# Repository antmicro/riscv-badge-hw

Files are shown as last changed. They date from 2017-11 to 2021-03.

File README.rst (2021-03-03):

==========================
RISC-V Electronic Badge HW
==========================

Copyright (c) 2017-2021 `Antmicro <https://www.antmicro.com>`_



Overview:
=========

This repository contains all the hardware design files required to build the RISC-V Electronic Badge development kit. The Badge allows for displaying text and graphics
on an e-Paper screen. The actual content to be displayed can be written to the EEPROM memory using an NFC programmer. The Badge contains a PCB module with a RISC-V based microcontroller
(SiFive's FE310) that reads the content of the EEPROM memory and transfers it to the e-Paper.

Key features:
=============

* 32-bit RISC-V based SiFive FE310 microcontroller placed on a tiny PCB module that can be re-used with a custom baseboard
* EG020BS011 2" e-Paper display
* NFC/RFID tag with 64Kbit EEPROM
* debug USB-JTAG/UART interface (FT4232H) allows the board to be used as an evaluation board
* battery powered (2x CR2032) / 5V over microUSB
* SiLabs EFR32-based ARTIK-030-AV1R IoT module with Bluetooth support (optional)

The device consists of two boards:

1. Badge board equipped with an e-Paper display and all the interfaces and peripherals (`FE310_Badge <FE310_Badge>`_ directory)
2. FE310 Module built around SiFive's FE310 RISC-V chip (`FE310_Module <FE310_Module>`_ directory)

The PCB projects were created in Altium Designer 14.1.

Software support:
=================

The software supporting this hardware platform can be found in a separate repository `here <https://github.com/antmicro/riscv-badge-application>`_.

Acknowledgements:
=================

This project was made possible thanks to the joint effort of Antmicro, SiFive and the RISC-V Foundation on the occasion of the 7th RISC-V Workshop.
If you have any questions, please write to contact@antmicro.com.

License
=======

`Apache-2.0 <LICENSE>`_

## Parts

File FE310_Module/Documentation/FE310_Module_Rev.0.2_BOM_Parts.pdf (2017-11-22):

# Bill of Materials

Project: | FE310 Module
Revision: | 0.2
Variant: | None
Creation Date: | 10/20/2017
Print Date: | 2017/11/22
Value | Footprint | Designator | Description | Manufacturer | Part Symbol | Quantity
100n | 0402 | C1, C2, C5, C6, C7, C8, C9, C10, C14 | MLCC SMT Capacitor 100nF 0402 | MULTICOMP | MC0402X104M100CT | 9
10u | 0402 | C3, C4, C13, C15, C18 | MLCC SMT Capacitor 10uF 0402 | TDK | C1005X5R0J106M050BC | 5 2
12p | 0402 | C11, C12 | MLCC SMT Capacitor 12pF 0402 | WALSIN | 0402N120J500CT
3n3 | 0402 | C16 | MLCC SMT Capacitor 3.3nF 0402 | MULTICOMP | MC0402B332K250CT | 1 1
22u | 0603 FE310-G000 | C17 IC1 | MLCC SMT Capacitor 22uF 0603 | MURATA FREEDOM | GRM188R60G226MEA0D FE310-G000 | 1 FE310-G000
IS25LP128 | WSON_6x5mm_8pin | IC2 | Flash Memory 128Mb QPI/QSPI, WSON, RoHS, ET | ISSI | IS25LP128-JKLE
SIT1533AC-H5-D14- 32.768D | SIT1533AC | IC3 | 32.768kHz LVCMOS MEMS (Silicon) Oscillator Surface Mount 1.2 V ~ 3.63 V 1.3µA | SiTIME | SIT1533AC-H5-D14-32.768D | 1
SC18IS600 | QFN-24_4X4MM MicroSIP | IC4 IC5 | IC SPI TO I2C BUS 24-HVQFN Voltage Regulators - Switching Regulators 3-A 17V Step-down Converter Module with | NXP | SC18IS600IBS,151 | 1 TPS82130

1

| | | Integrated Inductor 8-uSiP -40 to 125 | TEXAS INSTRUMENTS | TPS82130SILR | 1 1
AXK6F60347YG | AXK6F60347YG SC70-3 | J1 Q1 | CONN HEADER BRD/BRD .5MM 60POS MOSFET P-CH 30V 1.2A SC70-3 | PANASONIC ON Semiconductor | AXK6F60347YG NTS4173PT1G | 1 NTS4173PT1G
100R | 0402 | R1 | SMT Resistor 100R 0402 | BOURNS | CR0402-FX-1000GLF
100k | 0402 | R2, R6, R8 | SMT Resistor 100k 0402 | VISHAY | CRCW0402100KFKEDHP | 3 3
1k | 0402 | R3, R4, R5 | SMT Resistor 0402 | MULTICOMP | MCMR04X1001FTL

1

124k | 0402 SC70-3 | R7 T1 | SMT Resistor 124k 0402 MOSFET N-CH 20V 540MA SC70-3 | WALSIN Diodes Incorporated | WR04X1240FTL DMN2004WK-7 | 1 DMN2004WK-7 1 X22-16.000-12-30/30/- 40+85
CRYSTAL_X22_2.5x2mm | Y1 | MERCURY UNITED ELECTRONICS X22-16.000-12-30/30/-40+85 Crystal, 16 MHz, SMD, 2.5mm x 2mm, 30 ppm, 12 pF, 30 ppm, X22 Series | MERCURY UNITED ELECTRONICS | X22-16.000-12-30/30/-40+85 | 1
35 Approved | Notes

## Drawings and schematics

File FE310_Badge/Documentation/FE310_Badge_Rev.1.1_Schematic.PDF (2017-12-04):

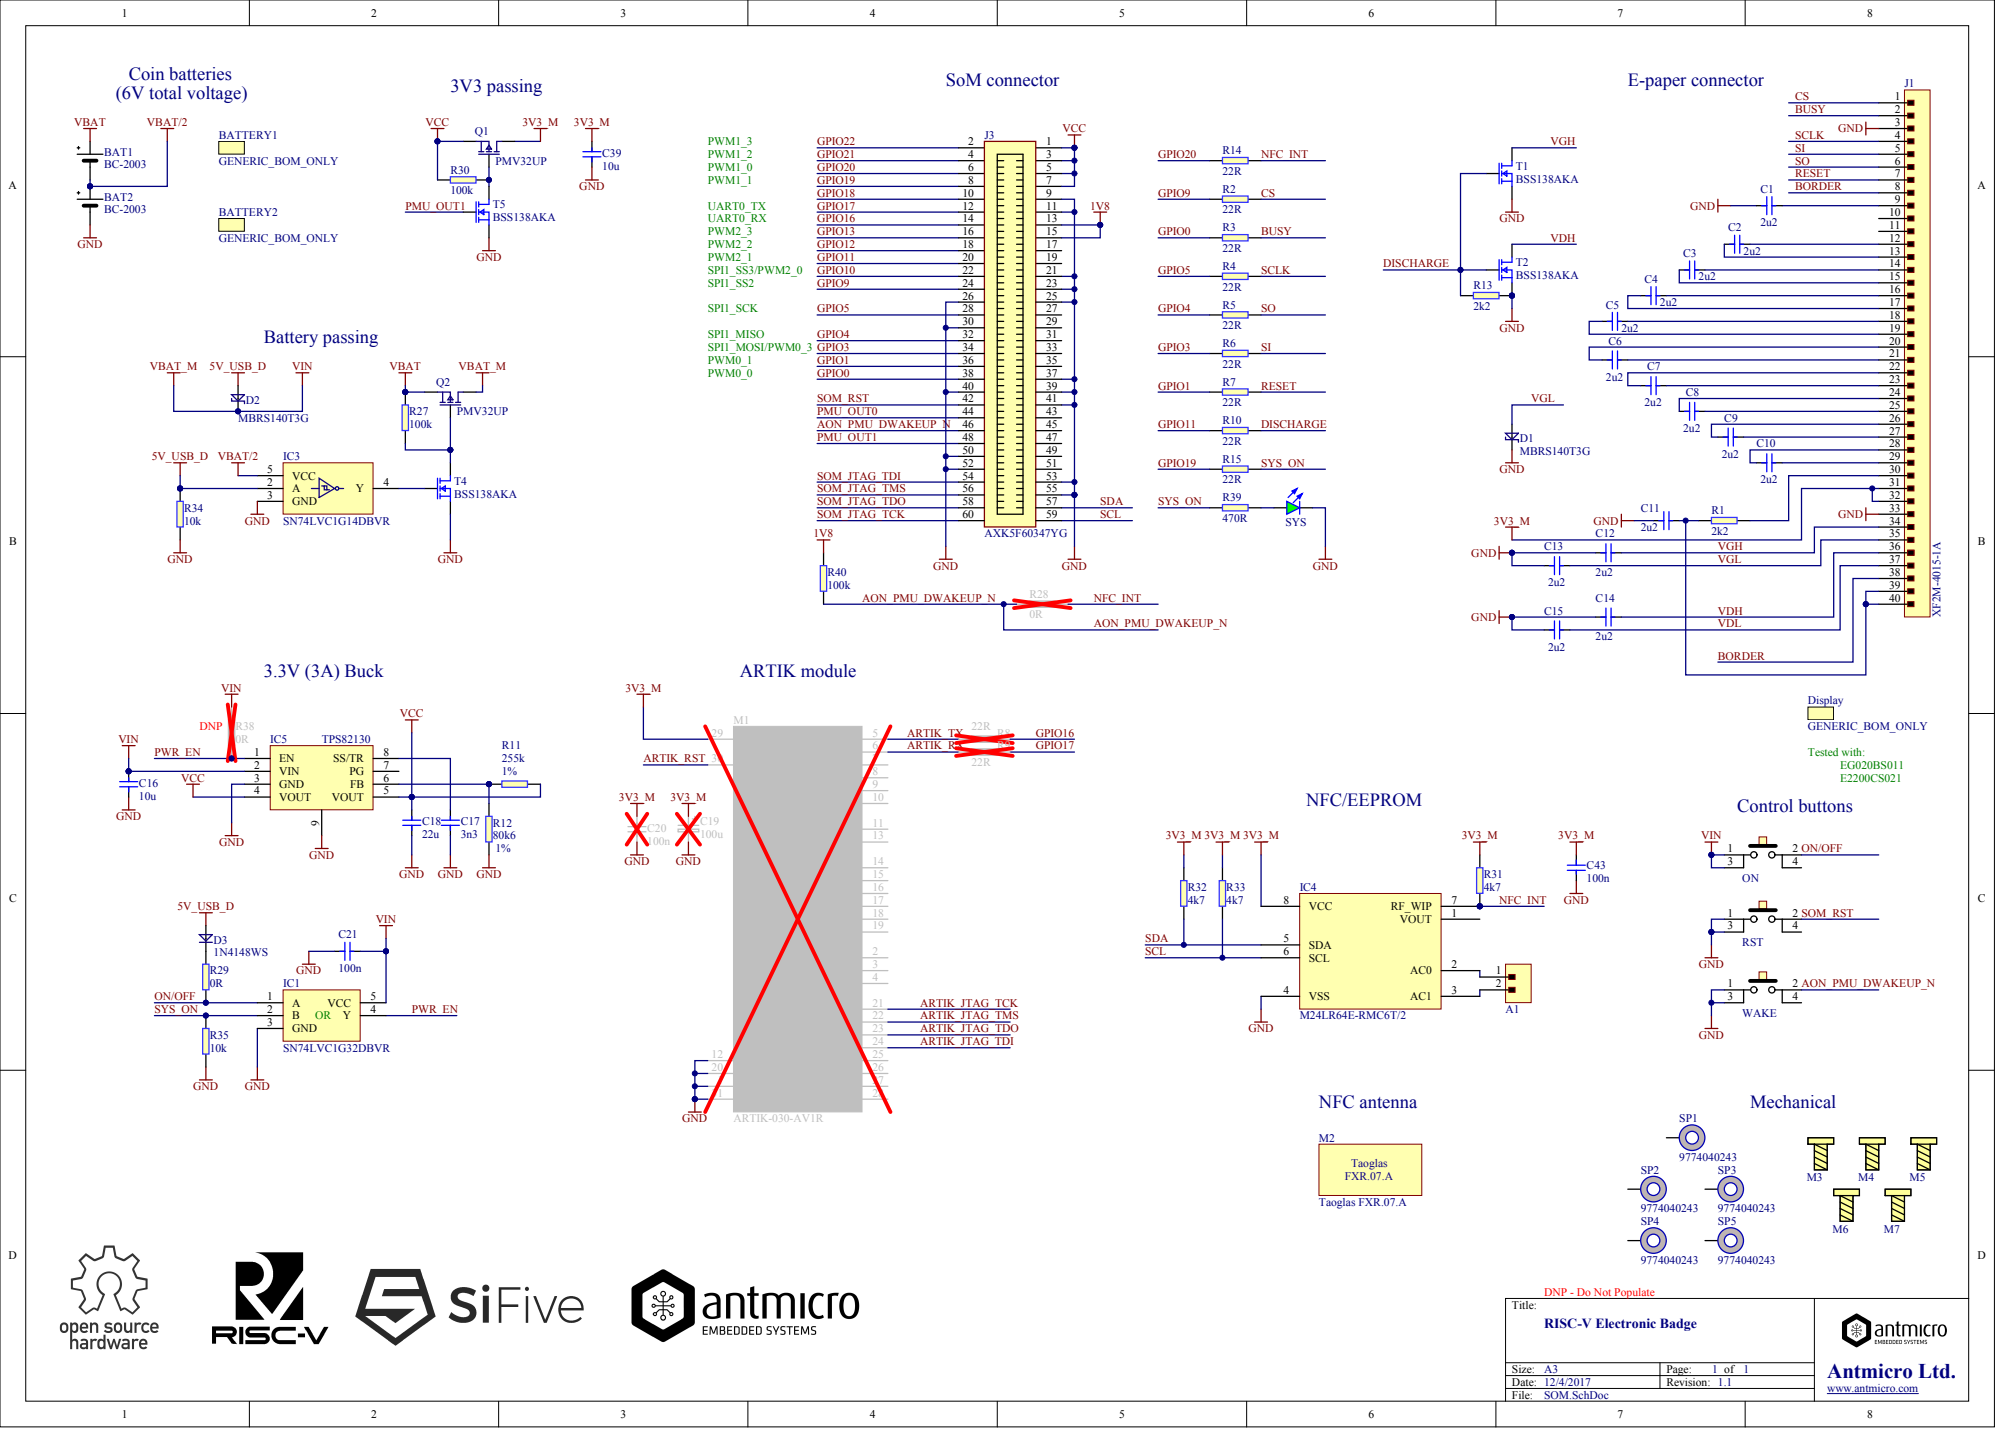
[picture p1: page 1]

VGL | 37

VDH | | 39

VDL

BORDER

GND 20

Title: RISC-V Electronic Badge | Antmicro Ltd. www.antmicro.com

DNP - Do Not Populate

Size: A3 | Page: 1 of 1
Date: 12/4/2017 | Revision: 1.1

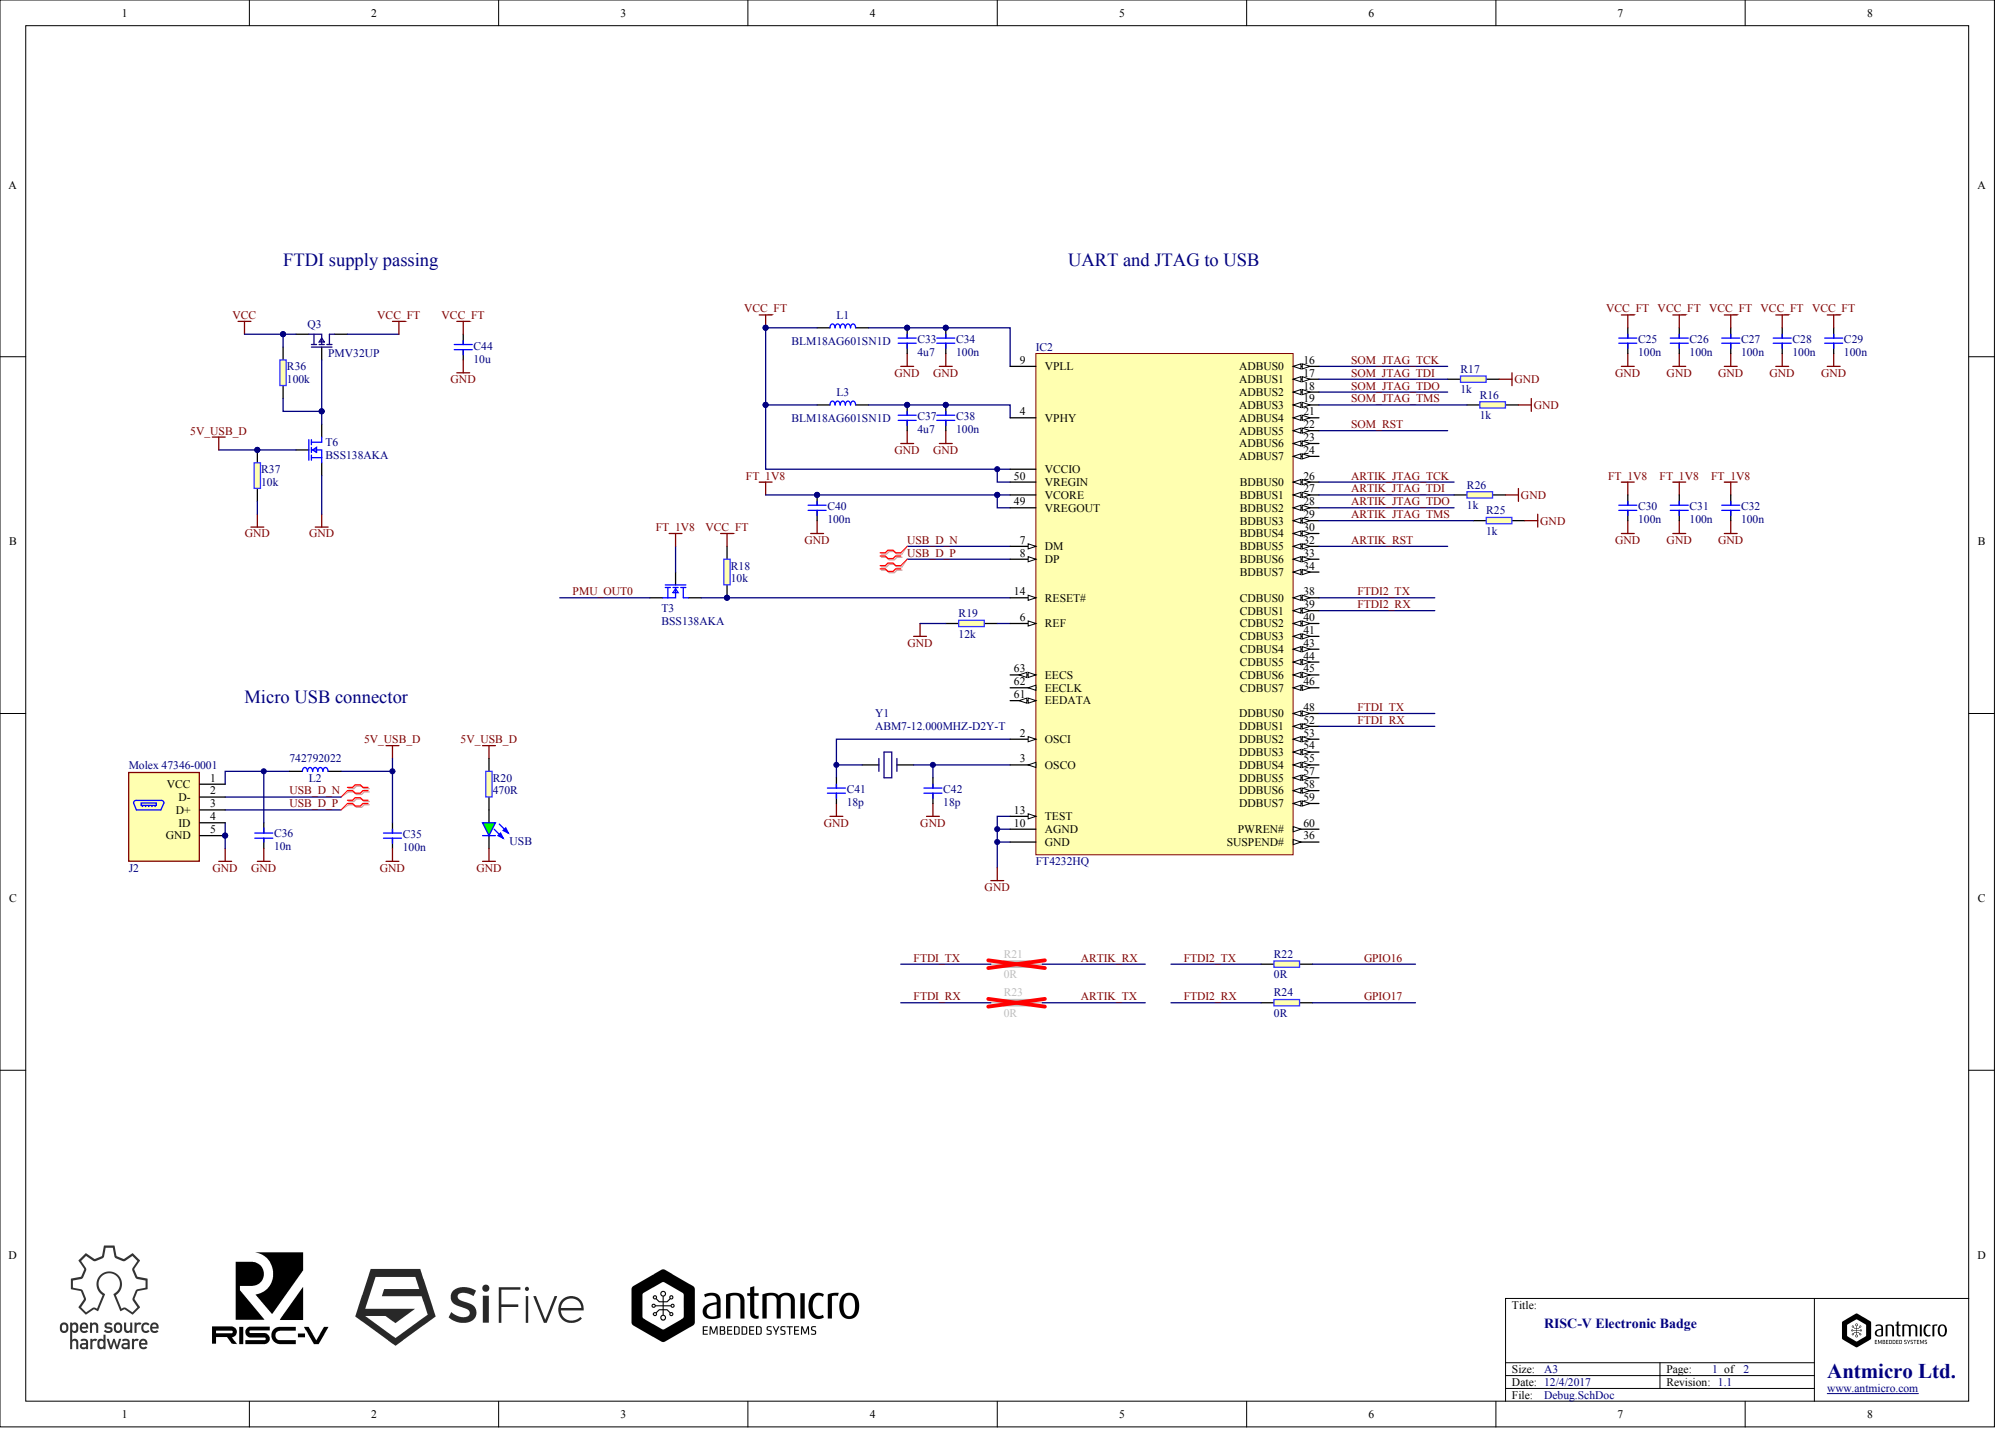
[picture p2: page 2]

UART and JTAG to USB

Title: RISC-V Electronic Badge | Antmicro Ltd. www.antmicro.com

Size: A3 | Page: 1 of 2
Date: 12/4/2017 | Revision: 1.1

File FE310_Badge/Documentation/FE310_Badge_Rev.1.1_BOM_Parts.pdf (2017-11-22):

# Bill of Materials

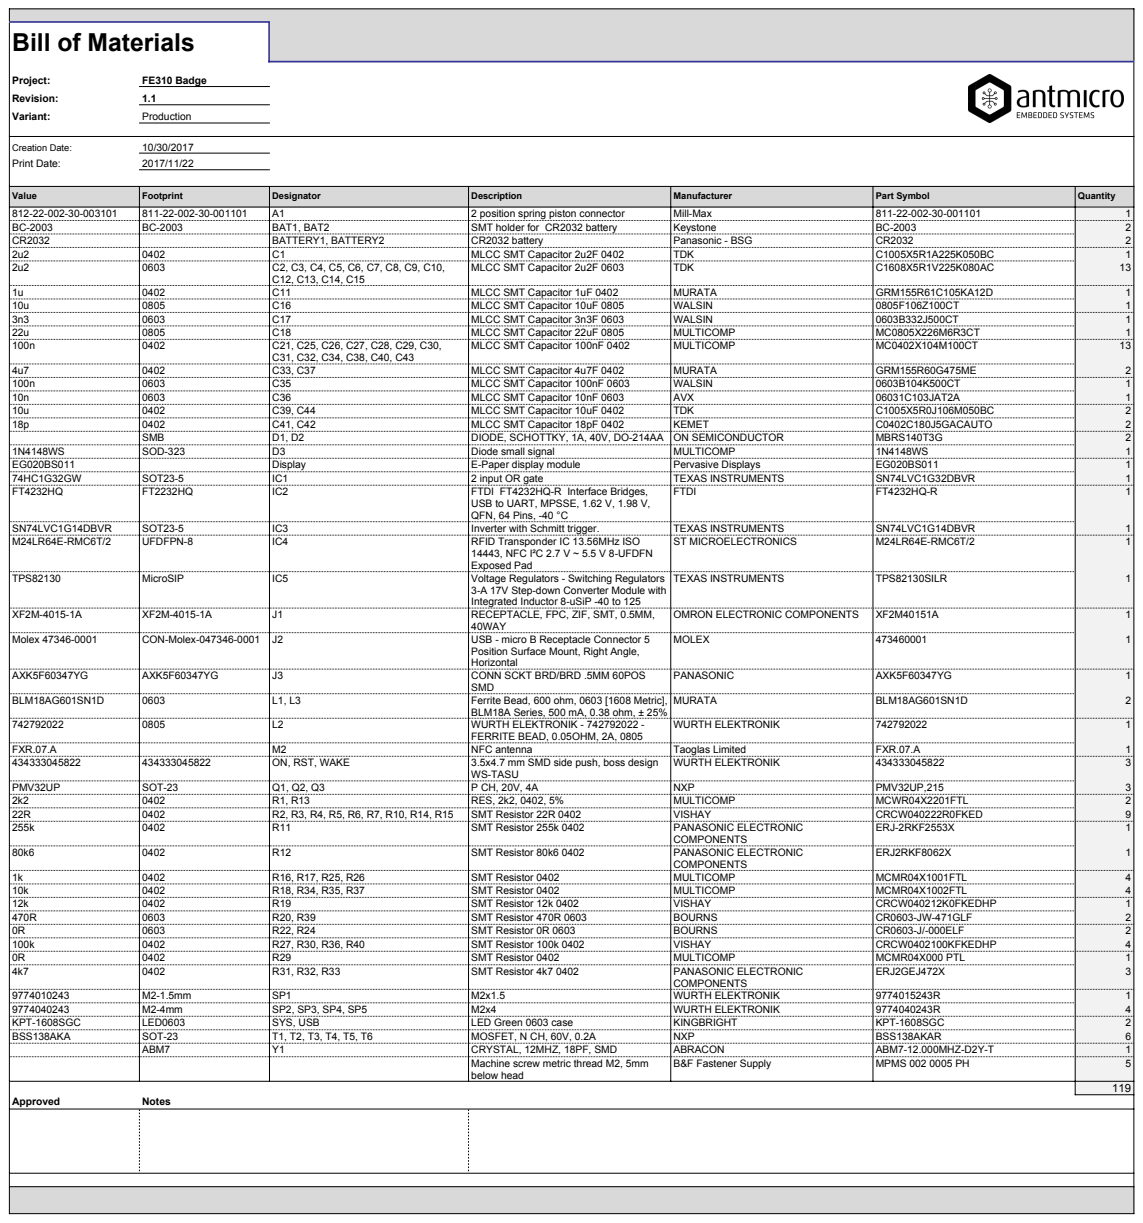
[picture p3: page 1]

Integrated Inductor 8-uSiP -40 to 125

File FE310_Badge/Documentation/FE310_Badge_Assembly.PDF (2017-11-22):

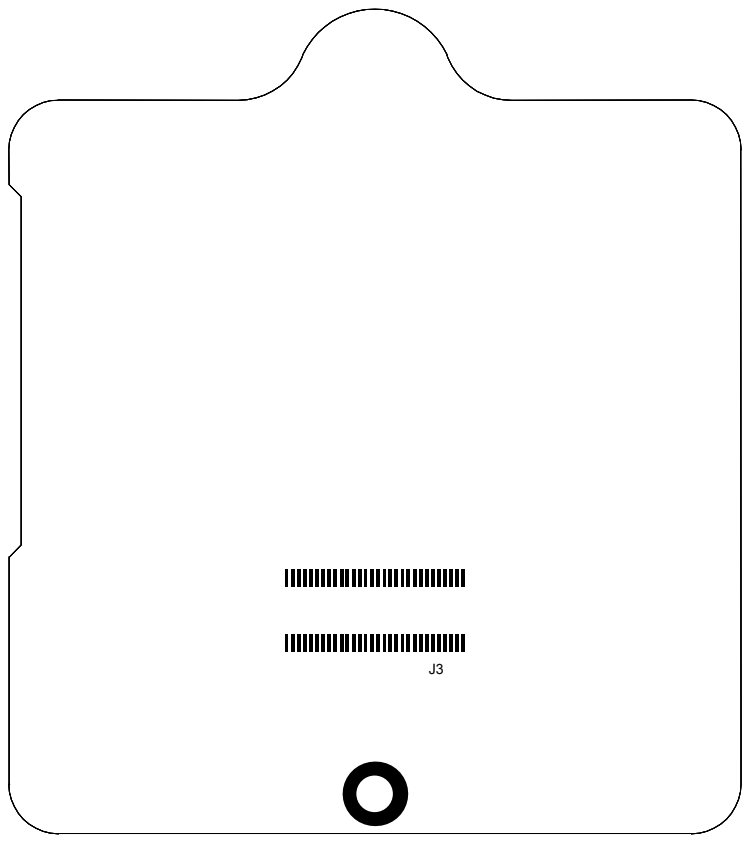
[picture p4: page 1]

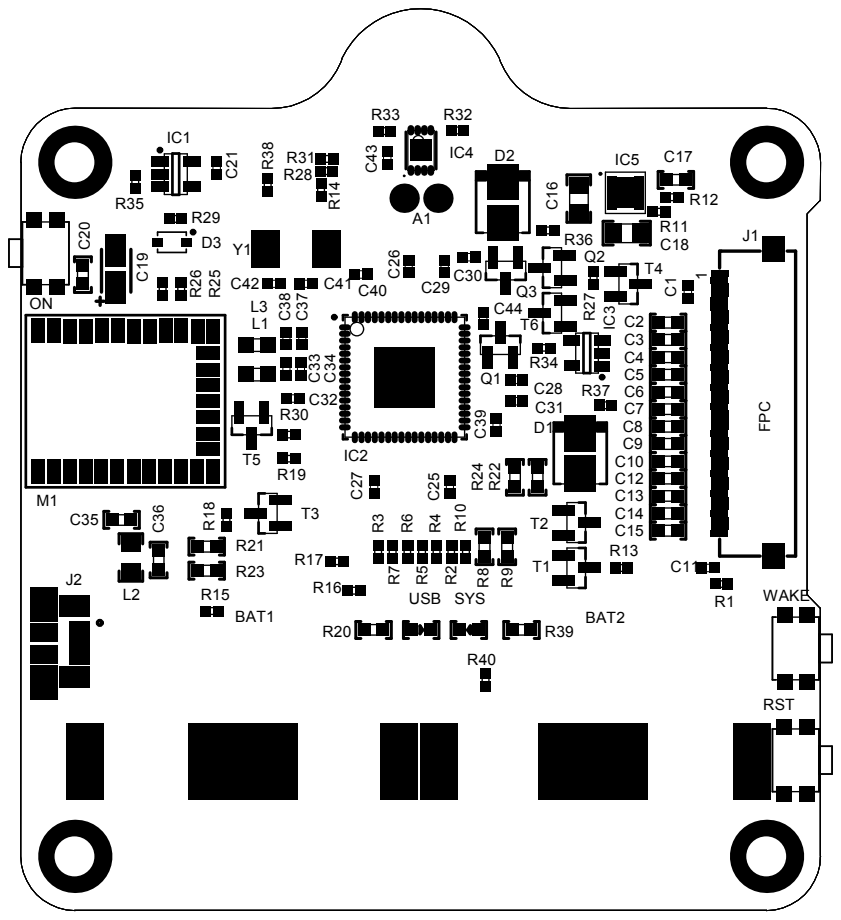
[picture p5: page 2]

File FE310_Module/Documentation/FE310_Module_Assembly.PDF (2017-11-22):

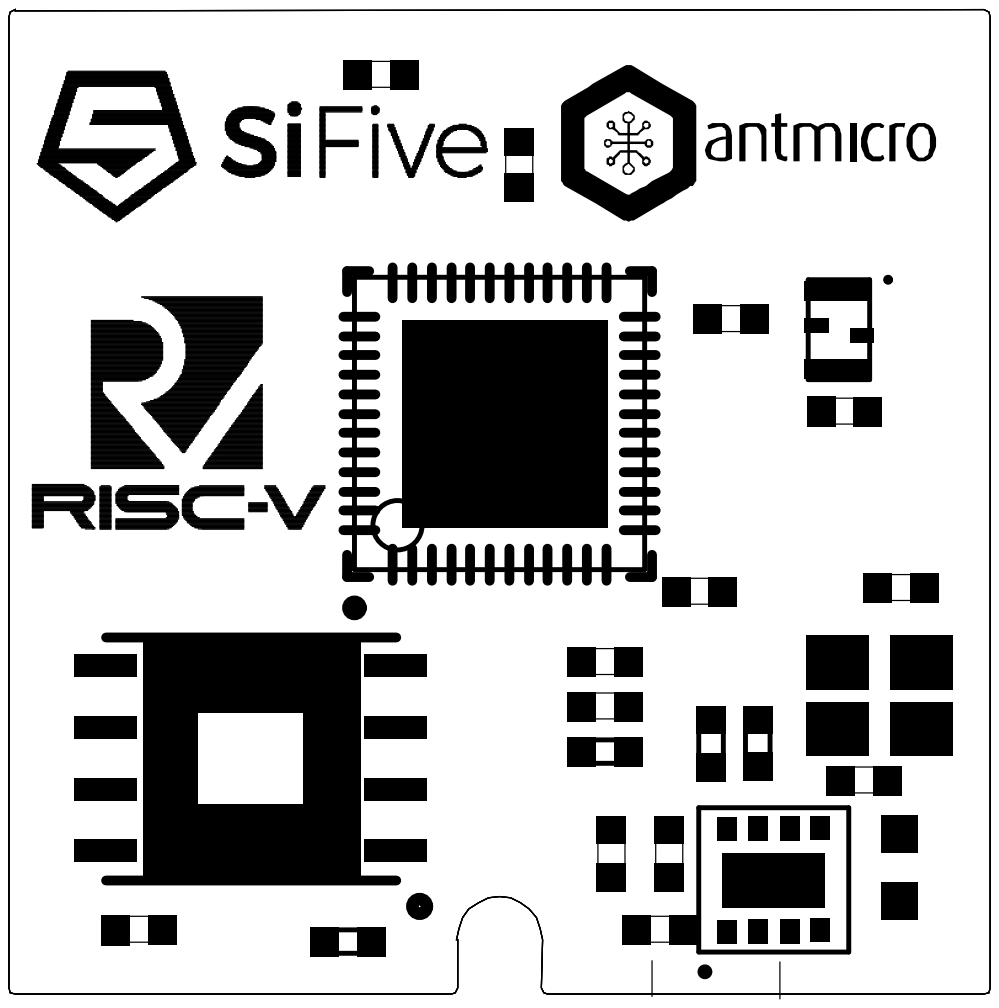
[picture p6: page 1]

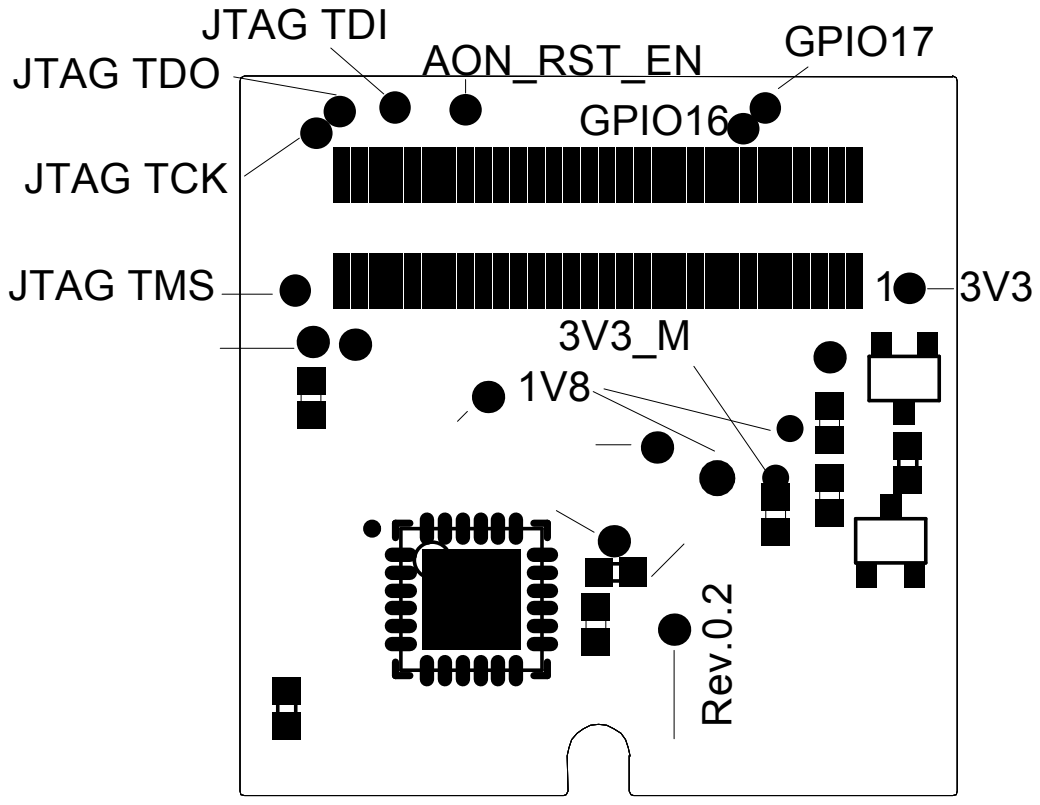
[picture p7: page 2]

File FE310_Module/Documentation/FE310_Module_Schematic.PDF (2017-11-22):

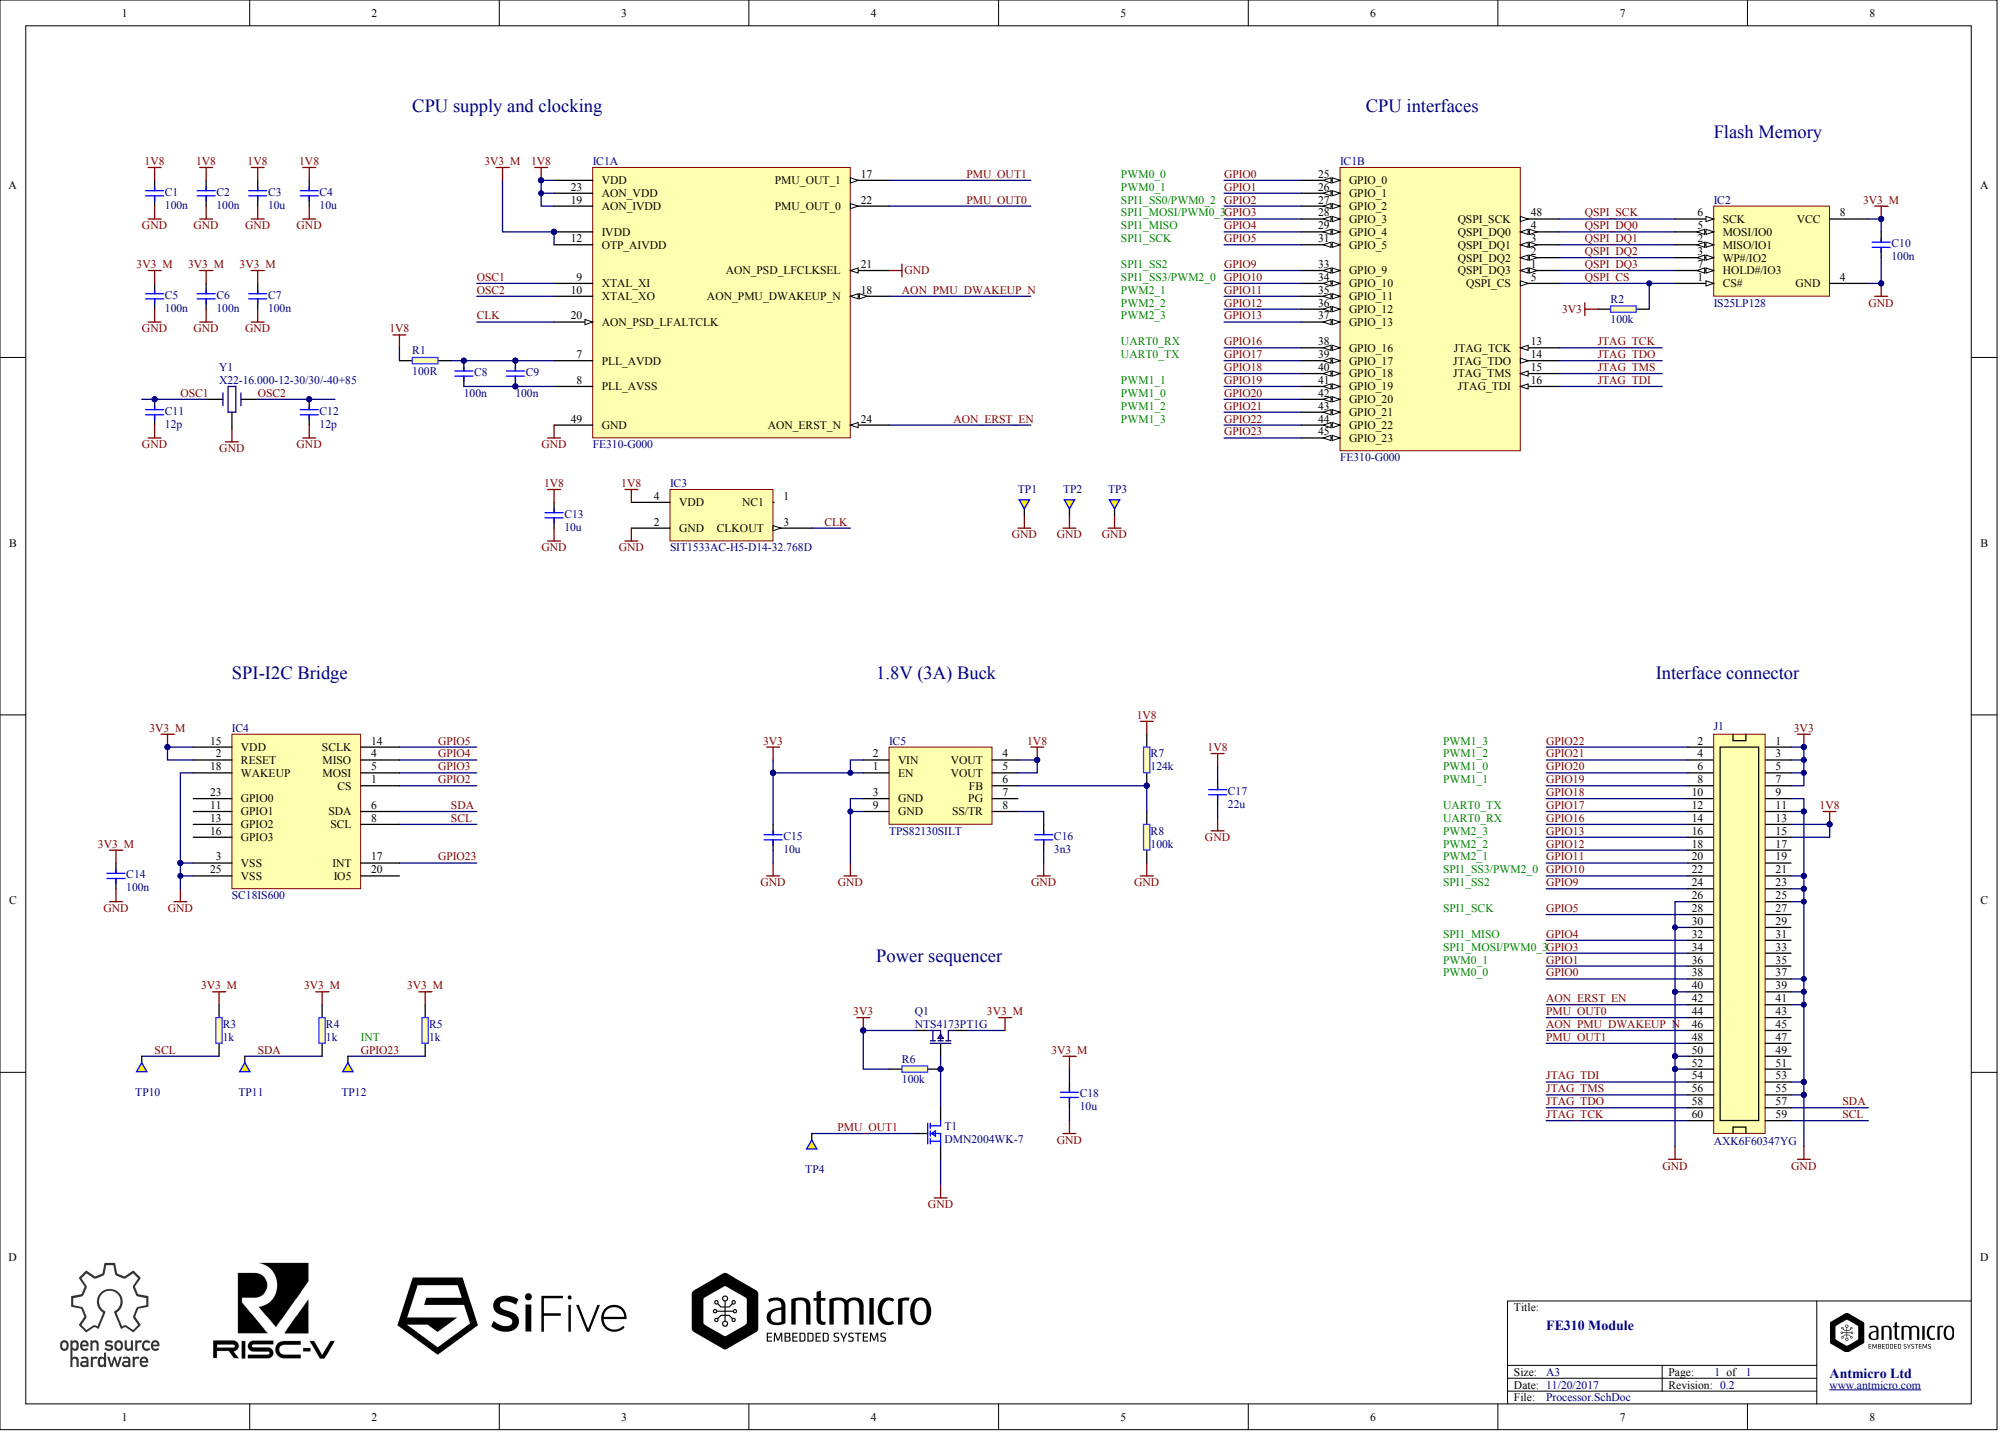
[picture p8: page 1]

CPU supply and clocking

55
57

Title: FE310 Module | Antmicro Ltd www.antmicro.com

Size: A3 | Page: 1 of 1
Date: 11/20/2017 | Revision: 0.2

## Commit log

2017-11-22 Initial commit.
    [Debug.SchDoc, FE310_Badge.PrjPcb, FE310_Module.PrjPcb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]
2017-12-04 Added information about alternative e-Paper display.
    [FE310_Badge.PrjPcb, SOM.SchDoc]
